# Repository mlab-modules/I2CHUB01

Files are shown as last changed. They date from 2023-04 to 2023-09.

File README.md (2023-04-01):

[Czech](./README.cs.md)
<!--- module --->
# I2CHUB01B
<!--- Emodule --->

<!--- subtitle ---> I2C (TWI) bus HUB <!--- Esubtitle --->

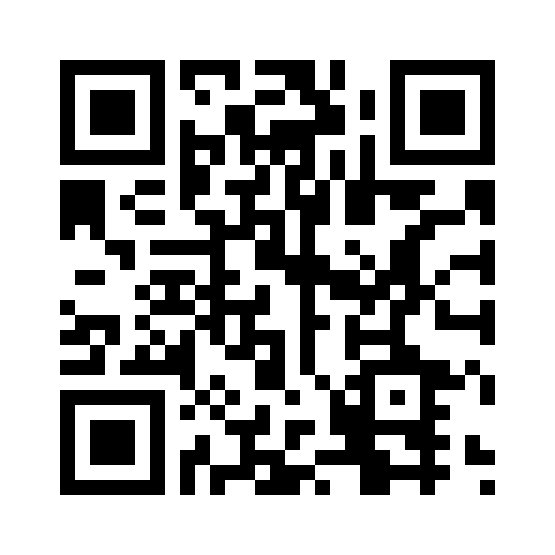
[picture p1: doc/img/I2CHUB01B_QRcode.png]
I2CHUB01B


<!--- description ---> The module allow conecting multiple I2C devices together. It does not consist any configurable IO. It is a simple bus multiplyer.<!--- Edescription --->

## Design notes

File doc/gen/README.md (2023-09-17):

# PCB

Board size: 19.81x40.13 mm (0.78x1.58 inches)

- This is the size of the rectangle that contains the board
- Thickness: 1.6 mm (63 mils)
- Material: FR4
- Finish: HAL
- Layers: 2
- Copper thickness: 35 µm

Solder mask: TOP / BOTTOM

- Color: Green

Silk screen: TOP / BOTTOM

- Color: White

# Important sizes

Clearance: 0.2 mm (8 mils)

Track width: 0.5 mm (20 mils)

- By design rules: 0.25 mm (10 mils)

Drill: 0.5 mm (20 mils)

- Vias: 0.5 mm (20 mils) [Design: 0.4 mm (16 mils)]
- Pads: 1.0 mm (39 mils)
- The above values are real drill sizes, they add 0.1 mm (4 mils) to plated holes (PTH)

Via: 0.8/0.4 mm (31/16 mils)

- By design rules: 0.7/0.3 mm (28/12 mils)
- Micro via: yes [0.3/0.1 mm (12/4 mils)]
- Buried/blind via: yes
- Total: 4 (thru: 4 buried/blind: 0 micro: 0)

Outer Annular Ring: 0.15 mm (6 mils)

- By design rules: 0.26 mm (10 mils)

Eurocircuits class: 4B
- Using min drill 0.5 mm for an OAR of 0.15 mm

# General stats

Components count: (SMD/THT)

- Top: 0/10 (THT)
- Bottom: 5/0 (SMD)

Defined tracks:

- 0.3 mm (12 mils)
- 0.4 mm (16 mils)
- 0.5 mm (20 mils)
- 0.6 mm (24 mils)

Used tracks:

- 0.5 mm (20 mils) (11) defined: yes
- 0.6 mm (24 mils) (46) defined: yes

Defined vias:

Used vias:

- 0.8/0.4 mm (31/16 mils) (Count: 4, Aspect: 2.0 A) defined: no

Holes (excluding vias):

- 0.89 mm (35 mils) (40)
- 3.0 mm (118 mils) (4)

Oval holes:

Drill tools (including vias and computing adjusts and rounding):

- 0.5 mm (20 mils) (4)
- 1.0 mm (39 mils) (40)
- 3.1 mm (122 mils) (4)

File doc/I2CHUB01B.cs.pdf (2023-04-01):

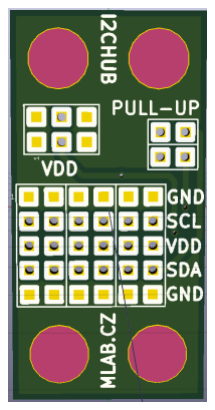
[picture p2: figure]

I2CHUB01B / 2018-11-05 / jacho/ http://www.mlab.cz | 1 / 4
I2CHUB01B | MLAB

# I2C HUB pro připojení až 6-ti zařízení

Jan Chroust

Modul neobsahuje žádné integrované obvody, pro řízení propojení.

### Slouží pro přímé propojení až 6-ti I2C zařízení. Součástí zapojení je možnost připojení pull-up rezistorů a ochrana úrovně napájení

pomocí diody.

# 1. Technické parametry

Parametr | Hodnota | Poznámka
Hlavní využití | I2C hub
Rozměry | 40.13 x 19.81 x 16 mm | Výška nad základní deskou

I2CHUB01B | MLAB

# 2. Popis konstrukce

Modul byl navržen jako svorkovnice pro propojení až 6-ti I2C zařízení pomocí konektoru pro I2C standardu MLAB. Jedná se o přímé propojení vodičů, bez použití integrovaných obvodů. V případě potřeby inteligentního I2CHUB byl navržen modul I2CHUB02B.

Do konstrukce byla zařazena možnost připojení pull-up rezistorů k datovým vodičům. Na modul je možné také přivést externí napájení pro I2C zařízení, které je možné chránit diodou (proti přepólování, nebe překročení úrovně napětí).

Modul může být použit například u meteorologických stanic, kde je potřeba k modulu I2DIFF připojit více senzorů.

I2CHUB01B | MLAB

# 3. Schéma

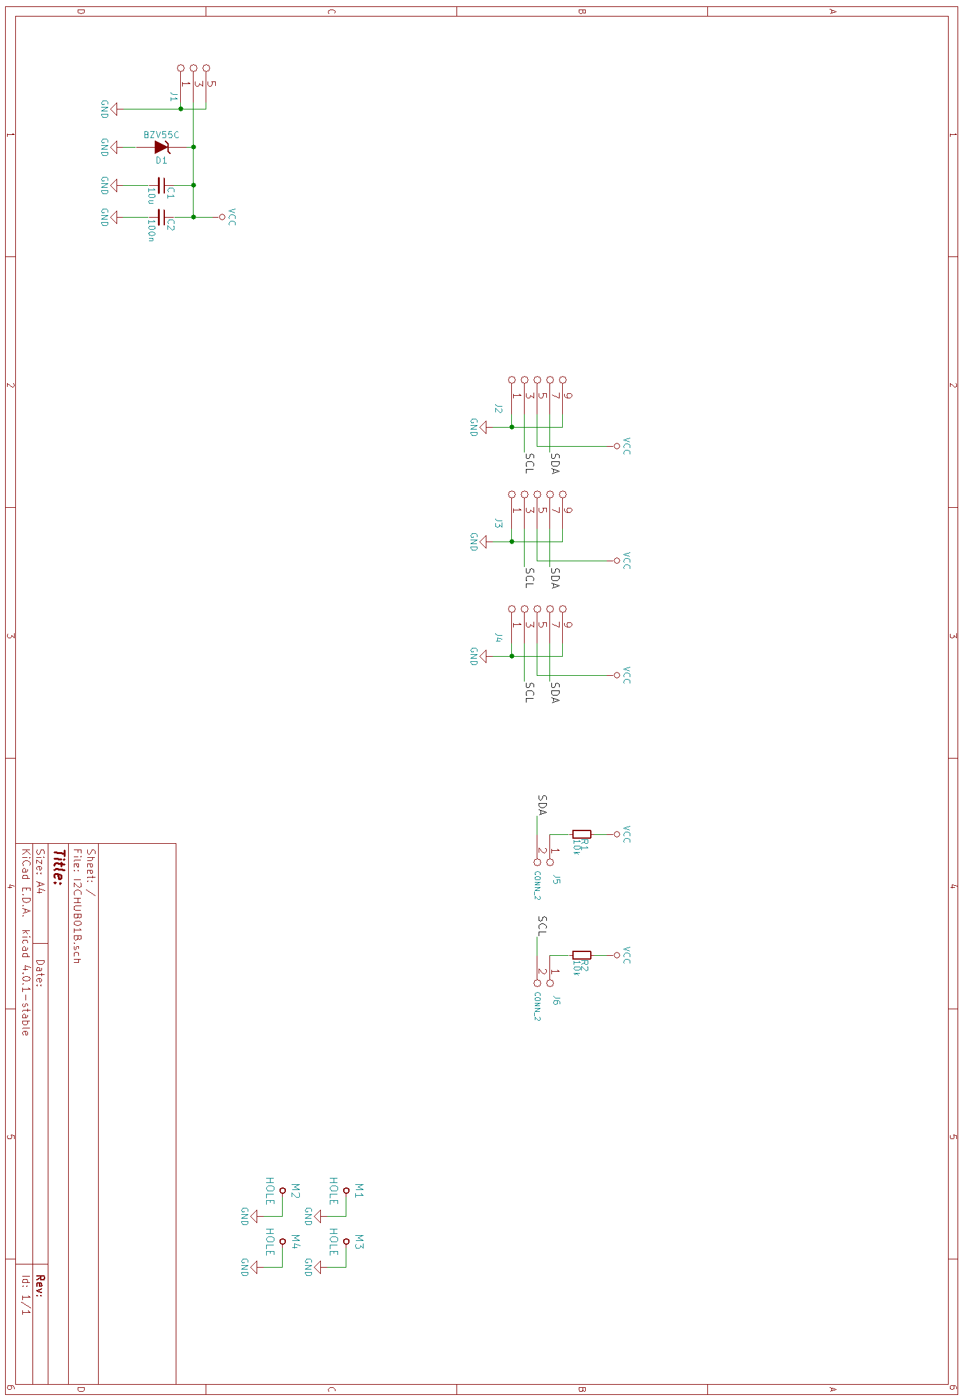
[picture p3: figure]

I2CHUB01B | MLAB

# 4. Osazení a oživení

## 4.1. Osazení

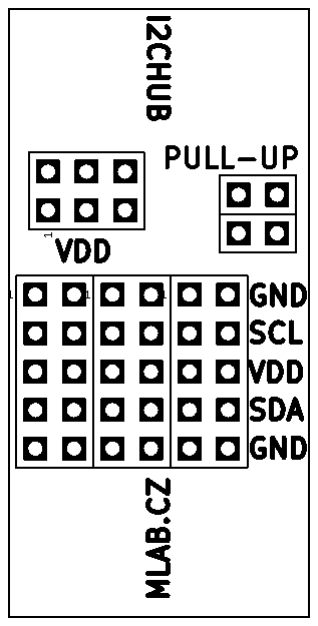
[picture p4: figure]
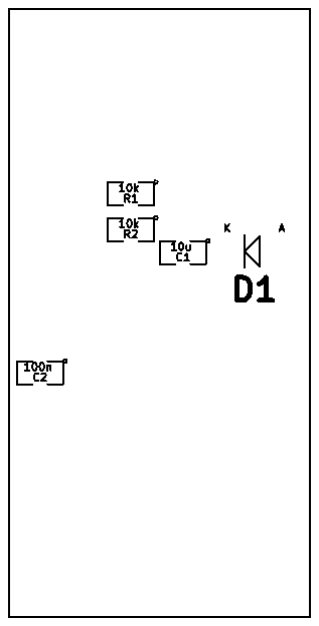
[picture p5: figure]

Označení | Typ | Pouzdro | Počet
C1 | 10u | SMD-0805 | 1
C2 | 100n | SMD-0805 | 1
D1 | BZV55C | Diode-MiniMELF_Standard | 1
J1 | JUMP_3X2 | Straight_2x03 | 1
J2,J3,J4 | JUMP_5X2 | Straight_2x05 | 3
J5,J6 | CONN_2 | Straight_1x02 | 2
R1,R2 | 10k | SMD-0805 | 2
M1,M2,M3,M4 | HOLE | MountingHole_3mm | 4

Diodu D1 je potřeba volit, dle potřebného napájecího napětí 3,6 V nebo 5,6 V.

## 4.2. Oživení

Po osazení modulu je dobré provést vizuální kontrolu, případně proměřit, zda na napájení není zkrat. Další oživení není potřeba.

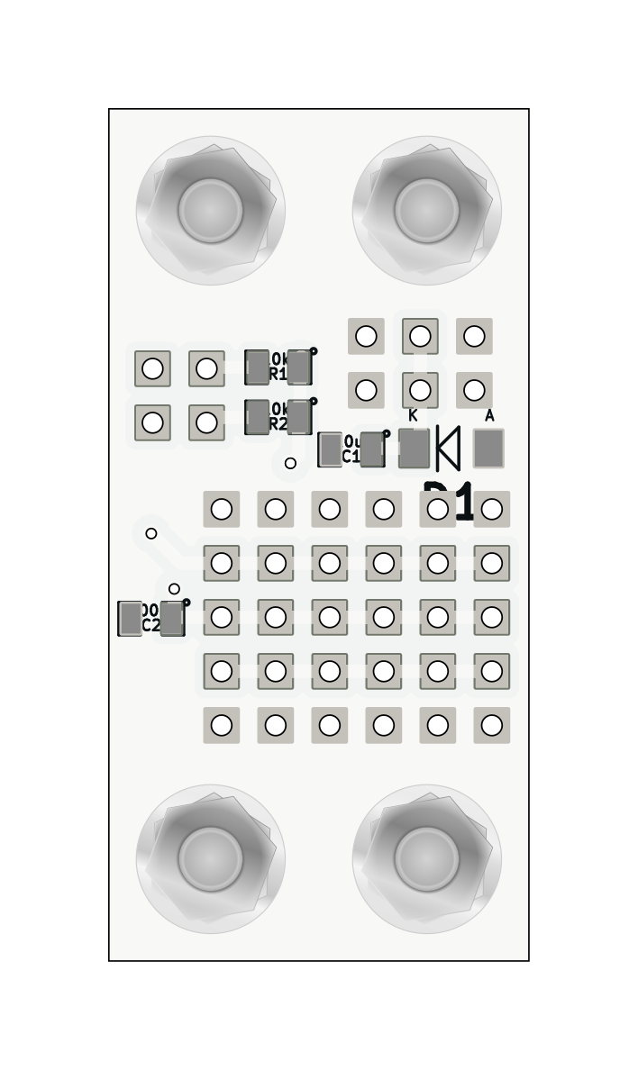
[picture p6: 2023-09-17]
doc/gen/img/I2CHUB01-bottom.png

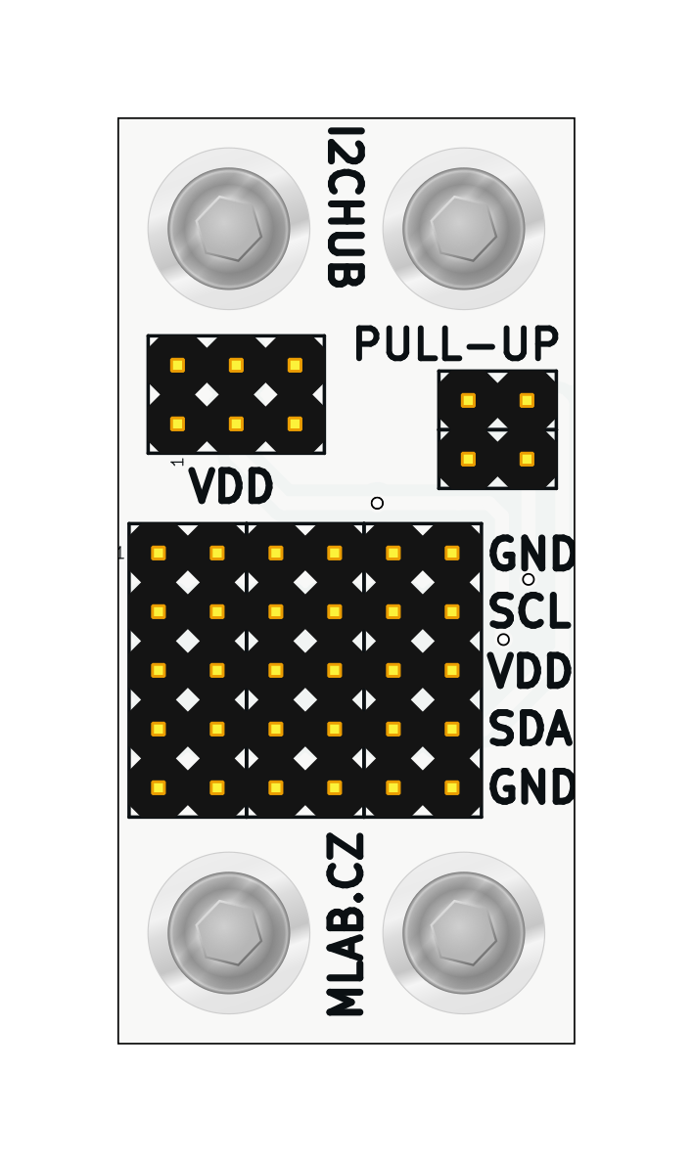
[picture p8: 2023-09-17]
doc/gen/img/I2CHUB01-top.png

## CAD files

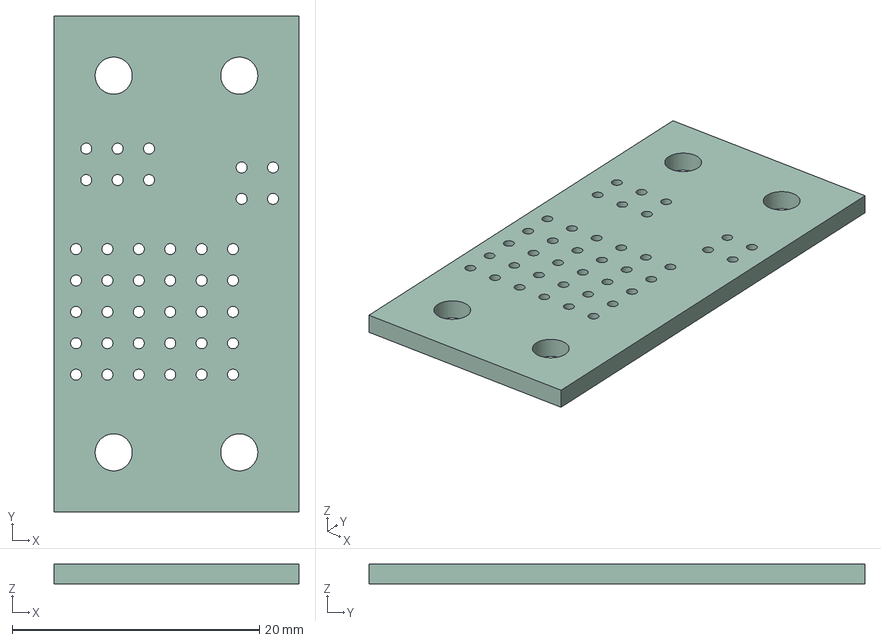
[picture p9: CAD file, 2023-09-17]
doc/gen/I2CHUB01.step
19.8 x 40.1 x 1.60 mm

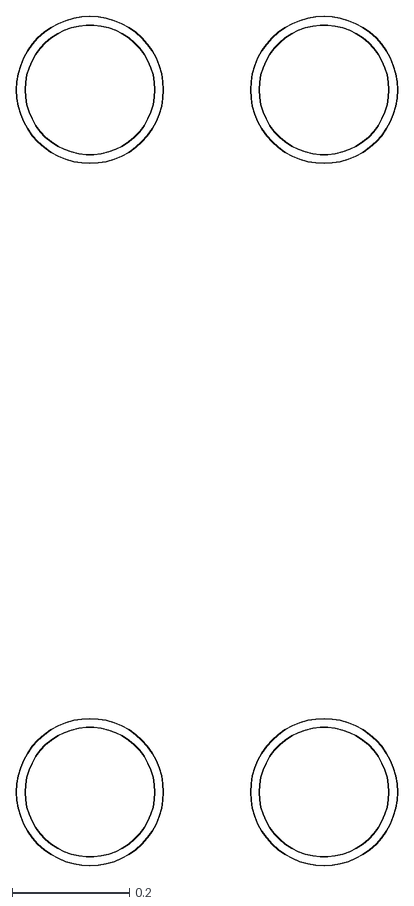
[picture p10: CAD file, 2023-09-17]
doc/gen/dxf/I2CHUB01-User_Comments.dxf
0.651 x 1.45

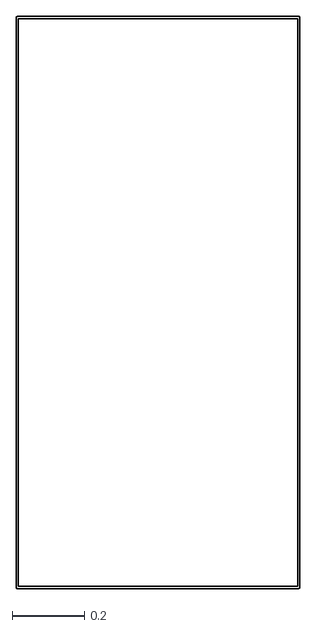
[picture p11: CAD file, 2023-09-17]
doc/gen/dxf/I2CHUB01-Edge_Cuts.dxf
0.786 x 1.59

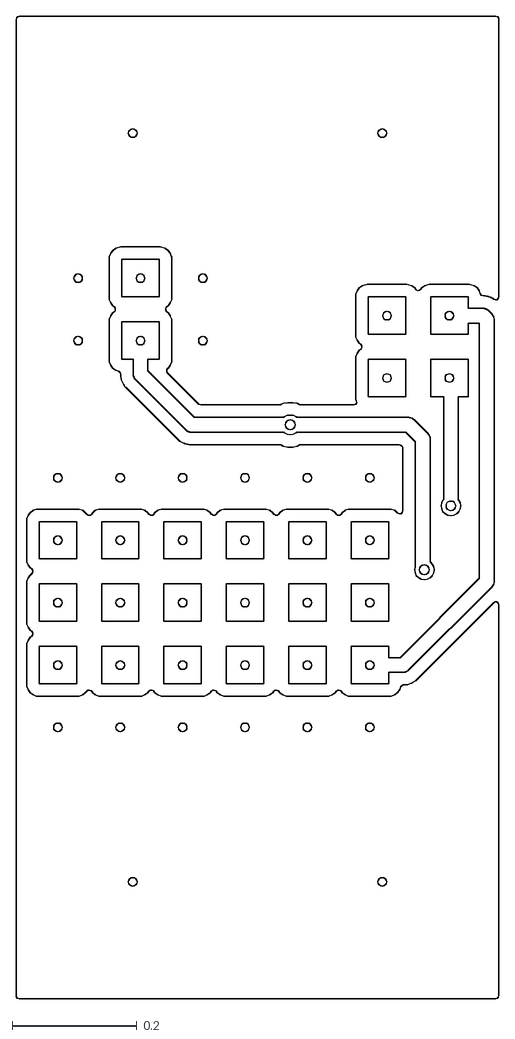
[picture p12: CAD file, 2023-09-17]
doc/gen/dxf/I2CHUB01-F_Cu.dxf
0.774 x 1.57

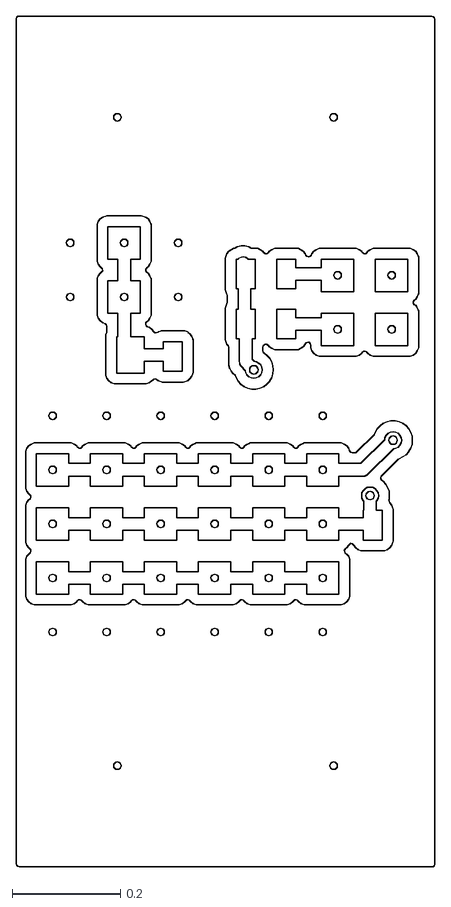
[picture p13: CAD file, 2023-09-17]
doc/gen/dxf/I2CHUB01-B_Cu.dxf
0.774 x 1.57

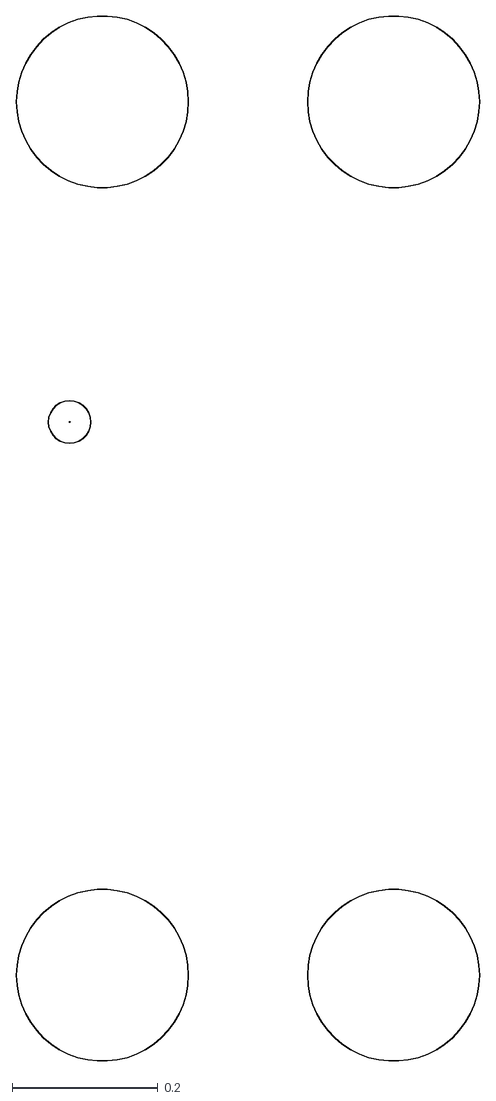
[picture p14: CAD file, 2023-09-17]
doc/gen/dxf/I2CHUB01-B_Adhesive.dxf
0.636 x 1.44

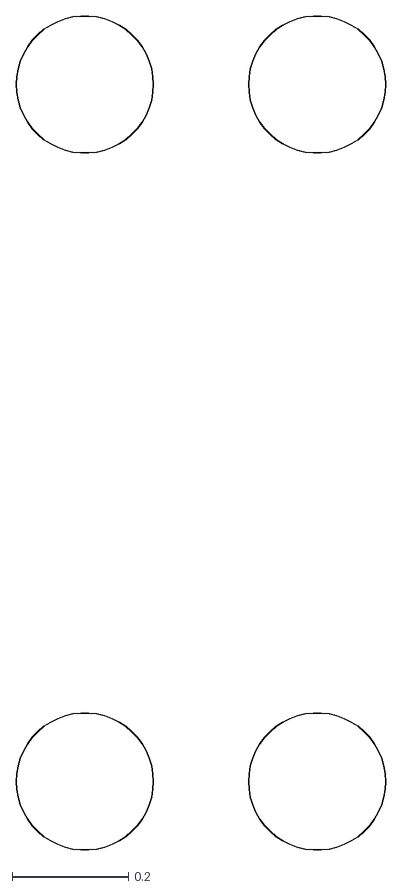
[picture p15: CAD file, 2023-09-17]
doc/gen/dxf/I2CHUB01-F_Adhesive.dxf
0.636 x 1.44

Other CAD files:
doc/gen/dxf/I2CHUB01-B_Courtyard.dxf
doc/gen/dxf/I2CHUB01-User_Eco1.dxf
doc/gen/dxf/I2CHUB01-F_Fab.dxf
doc/gen/dxf/I2CHUB01-F_Courtyard.dxf
doc/gen/dxf/I2CHUB01-B_Fab.dxf
doc/gen/dxf/I2CHUB01-User_Eco2.dxf
doc/gen/dxf/I2CHUB01-Margin.dxf
doc/gen/dxf/I2CHUB01-User_Drawings.dxf
doc/gen/dxf/I2CHUB01-B_Mask.dxf
doc/gen/dxf/I2CHUB01-B_Paste.dxf
doc/gen/dxf/I2CHUB01-B_Silkscreen.dxf
doc/gen/dxf/I2CHUB01-F_Mask.dxf
doc/gen/dxf/I2CHUB01-F_Paste.dxf
doc/gen/dxf/I2CHUB01-F_Silkscreen.dxf

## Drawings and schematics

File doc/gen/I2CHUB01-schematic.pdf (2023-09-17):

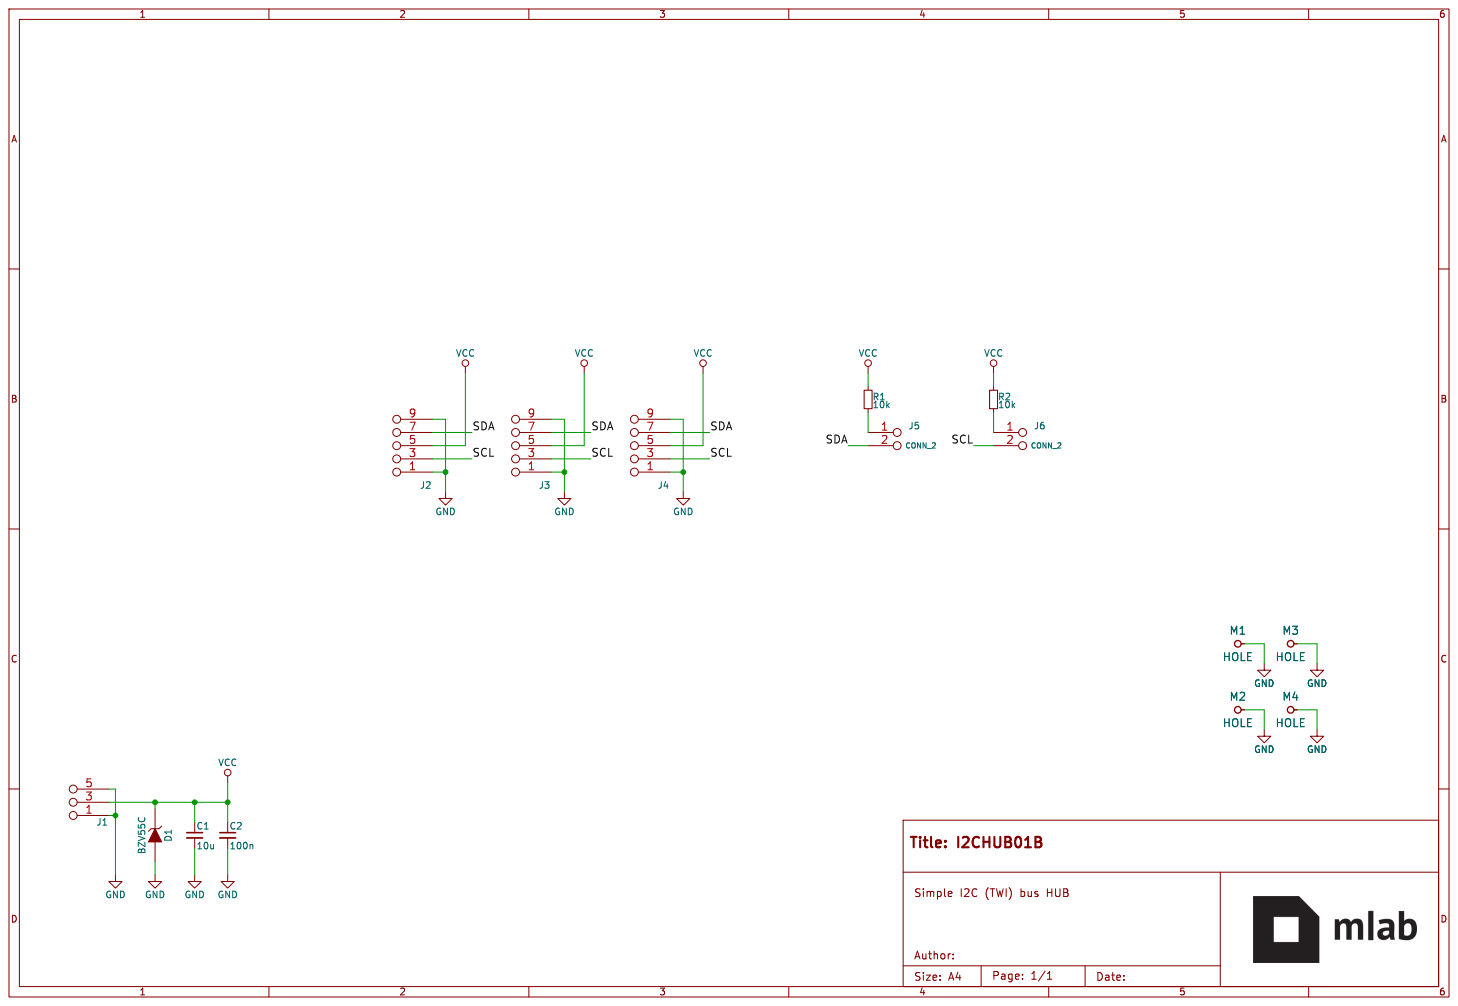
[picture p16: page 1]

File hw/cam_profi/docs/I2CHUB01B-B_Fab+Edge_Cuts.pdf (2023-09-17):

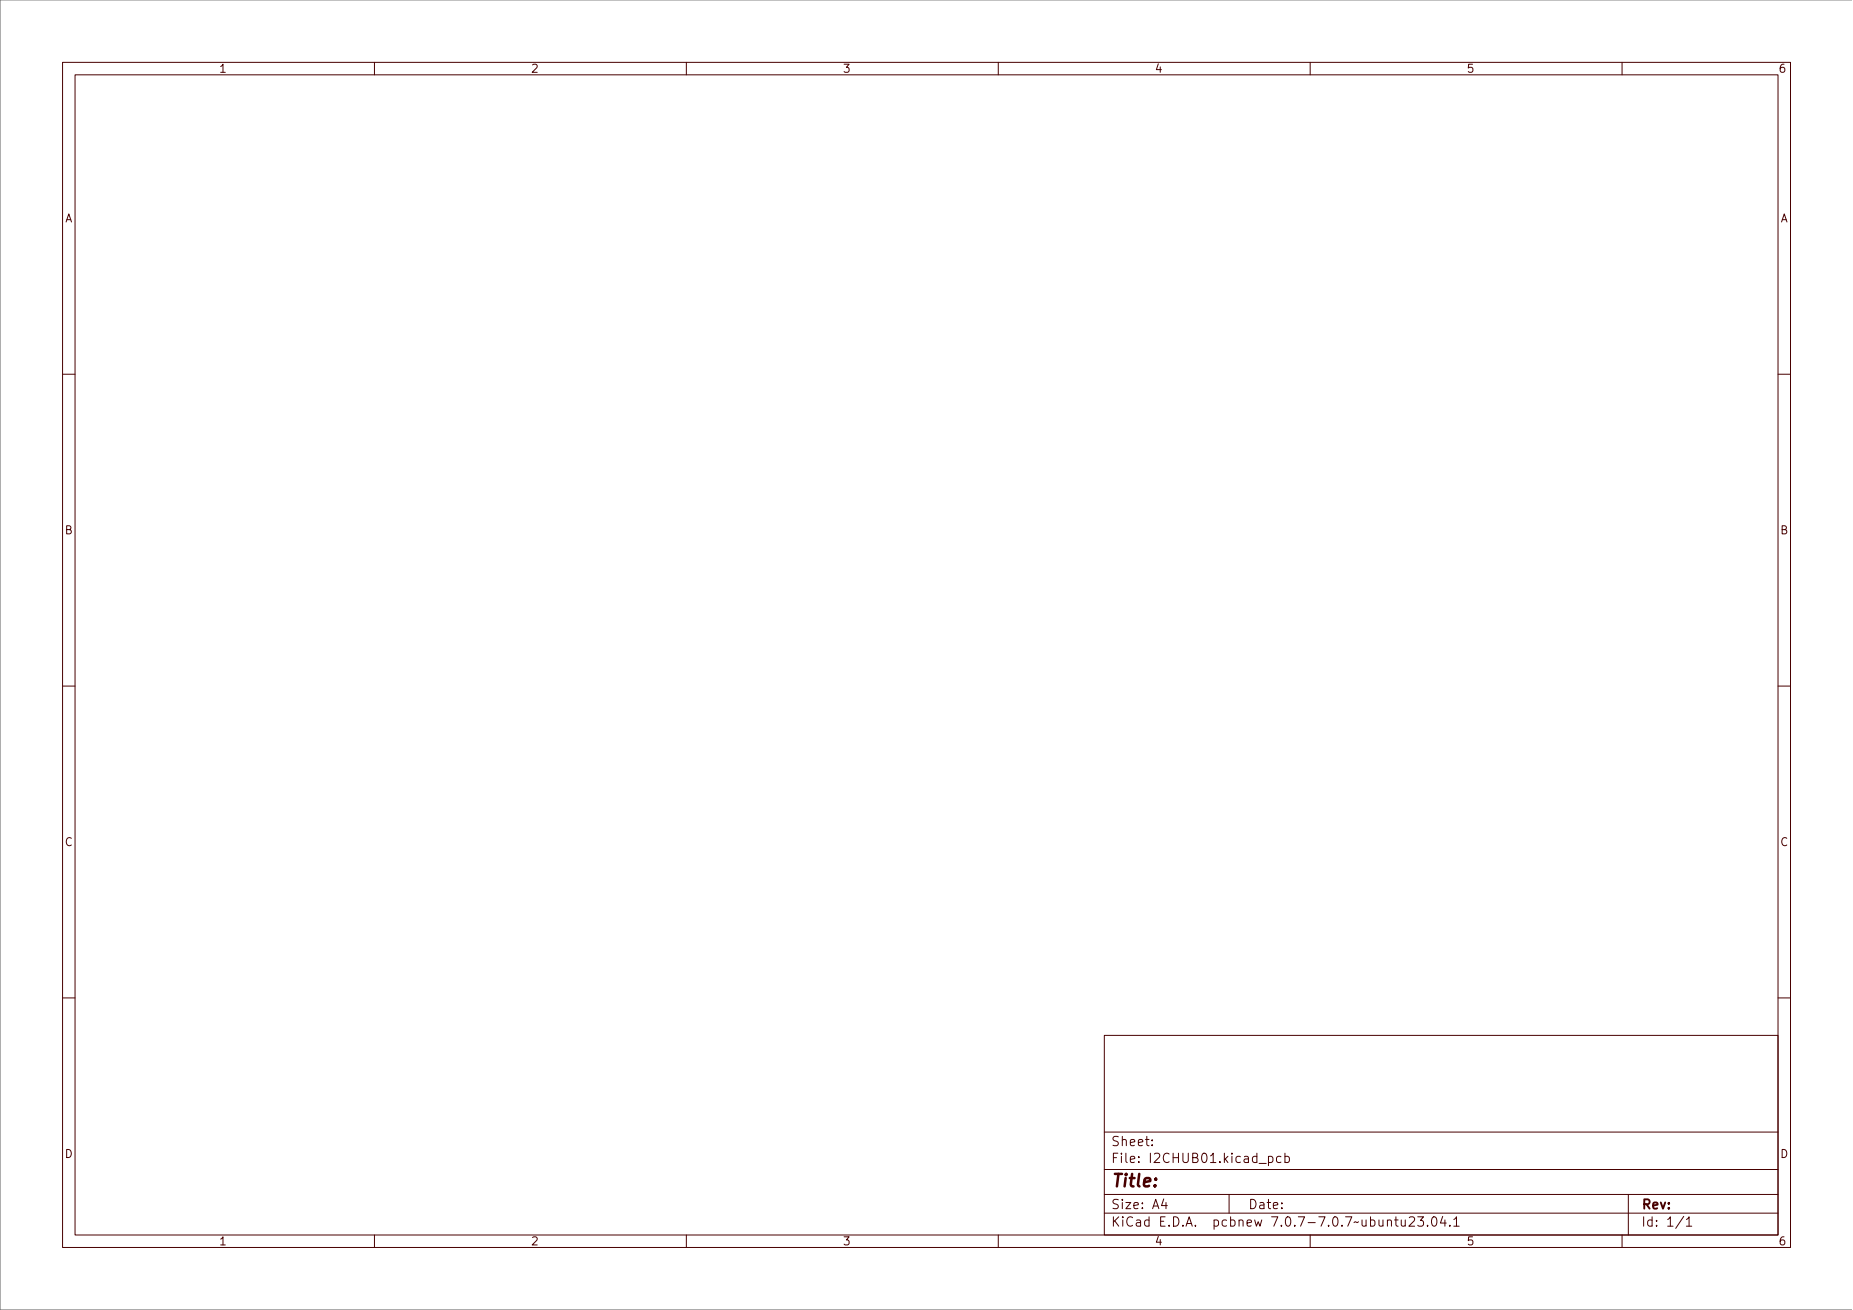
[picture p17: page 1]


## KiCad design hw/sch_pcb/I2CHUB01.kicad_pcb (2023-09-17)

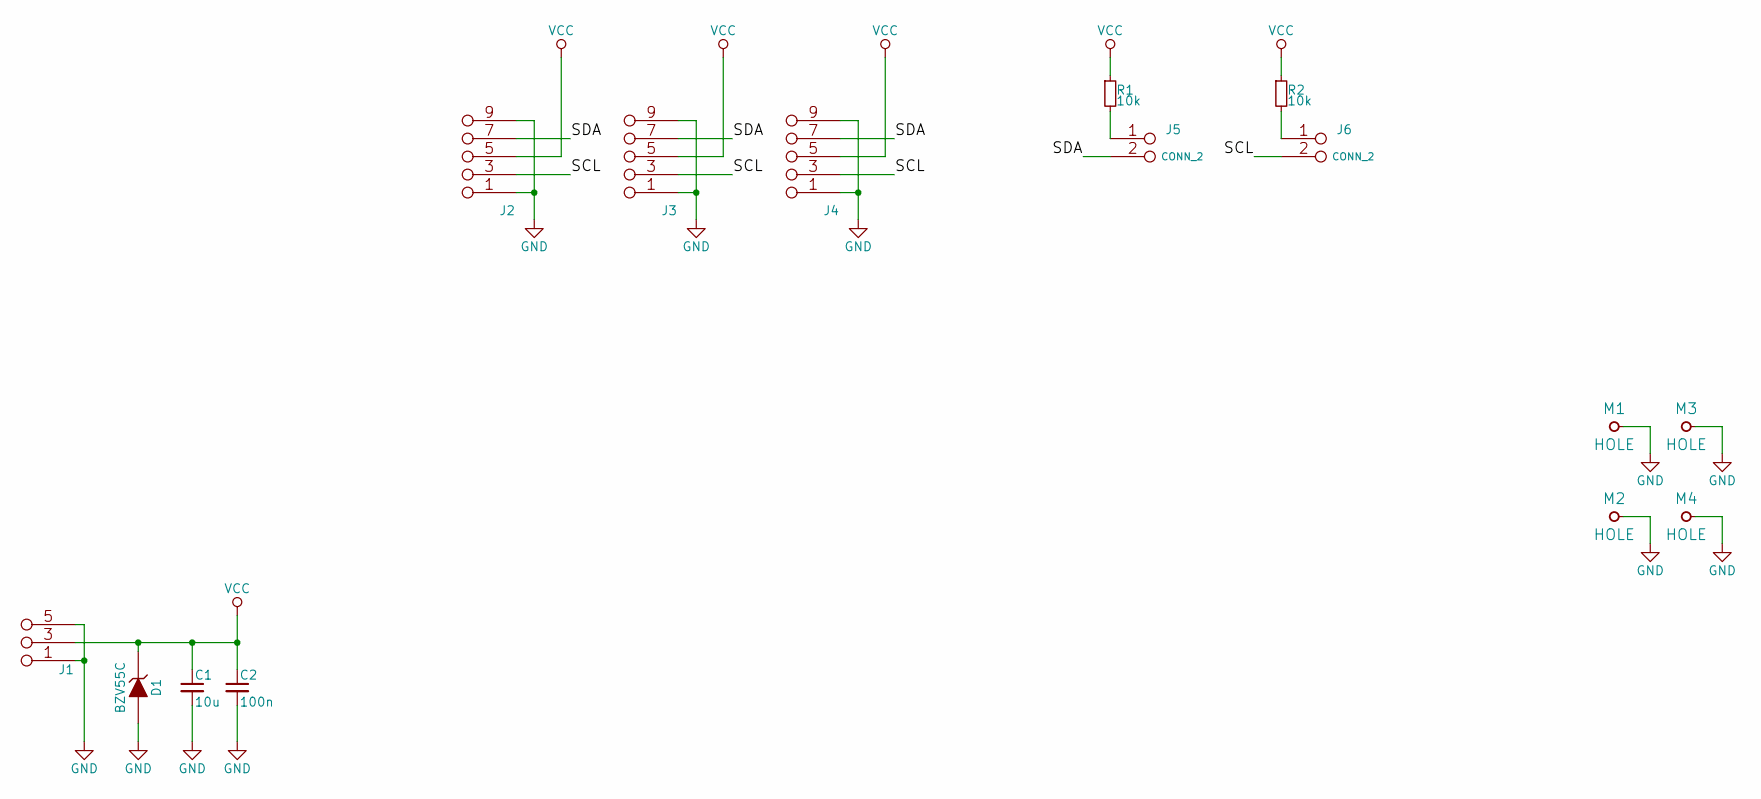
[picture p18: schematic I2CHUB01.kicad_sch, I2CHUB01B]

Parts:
C1: 10u; SMD-0805
C2: 100n; SMD-0805
D1: BZV55C; Diode-MiniMELF_Standard
J1: JUMP_3X2; Straight_2x03
J2, J3, J4: JUMP_5X2; Straight_2x05
J5, J6: CONN_2; Straight_1x02
M1, M2, M3, M4: HOLE; MountingHole_3mm
R1, R2: 10k; SMD-0805

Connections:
/SCL: J2.3 (4), J2.4, J3.3 (4), J3.4, J4.3 (4), J4.4, J6.2 (PM)
/SDA: J2.7, J2.8 (7), J3.7, J3.8 (7), J4.7, J4.8 (7), J5.2 (PM)
GND: C1.2, C2.2, D1.1 (A), J1.1 (2), J1.2, J1.5 (6), J1.6, J2.1 (2), J2.2, J2.9 (10), J2.10, J3.1 (2), J3.2, J3.9 (10), J3.10, J4.1 (2), J4.2, J4.9 (10), J4.10, M1.1, M2.1, M3.1, M4.1
unnamed: J5.1, R1.2
unnamed: J6.1, R2.2
VCC: C1.1, C2.1, D1.2 (K), J1.3 (4), J1.4, J2.5 (6), J2.6, J3.5 (6), J3.6, J4.5 (6), J4.6, R1.1, R2.1

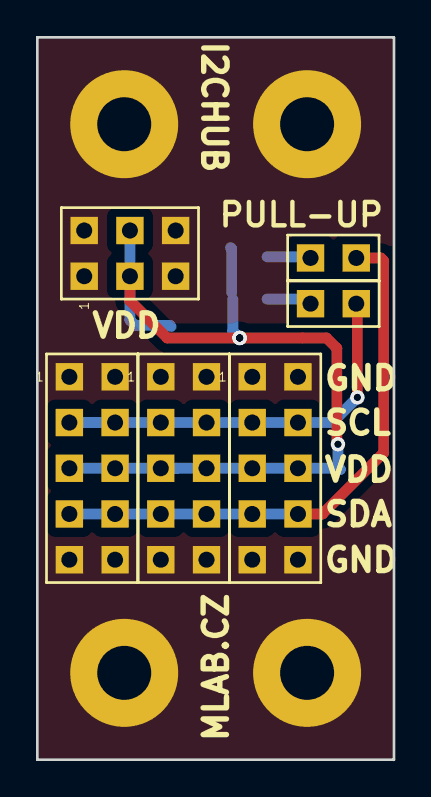
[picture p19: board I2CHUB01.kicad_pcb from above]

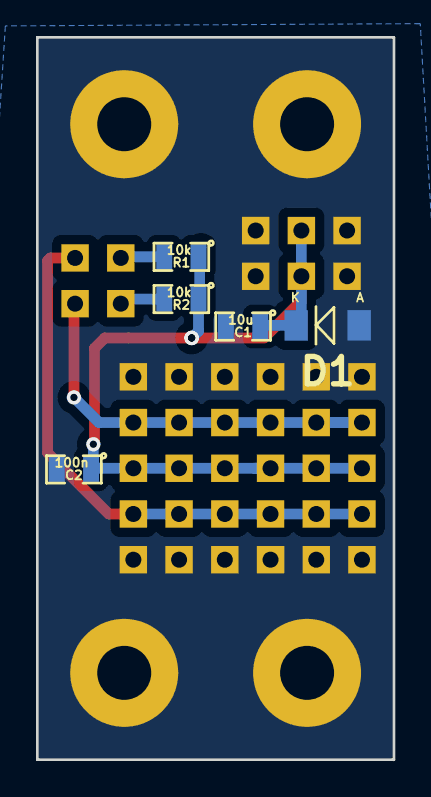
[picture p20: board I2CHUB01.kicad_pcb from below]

Board: 2 copper layers, 19.8 x 40.1 mm, 15 parts (5 on the bottom side), 6 nets.

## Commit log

2023-04-01 Adding force option to enable splitting in not fresh copy of Modules repository.
    [I2CHUB01B.kicad_pcb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]
2023-09-17 Convert project to KiCAD7.
    [I2CHUB01.kicad_pcb, I2CHUB01.kicad_sch, I2CHUB01B.kicad_pcb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]
2023-09-17 Update actions products
    [I2CHUB01-B_Adhesive.dxf, I2CHUB01-B_Courtyard.dxf, I2CHUB01-B_Cu.dxf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]
